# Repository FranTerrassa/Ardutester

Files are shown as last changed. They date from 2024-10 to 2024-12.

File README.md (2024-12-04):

## Projecto: {Ardutester}

Un comprobador de componentes Arduino basado en https://create.arduino.cc/projecthub/plouc68000/ardutester-v1-13-the-arduino-uno-transistor-tester-dbafb4

El autor original de este proyecto es [plouc68000](https://projecthub.arduino.cc/plouc68000) quien hizo el diseño y el codigo ardutester v1.13, aquien le doy todo el agradecimiento por este proyecto para la comunidad. También se a consultado este otro link [Mundo Yakara](https://www.youtube.com/watch?v=iBbuWZ-2Ljg&t=707sNo), gracias yakara por esos grandes videos. No es un proyecto propio, pero si he diseñado la PCB y fabricado siguiendo el esquema original.

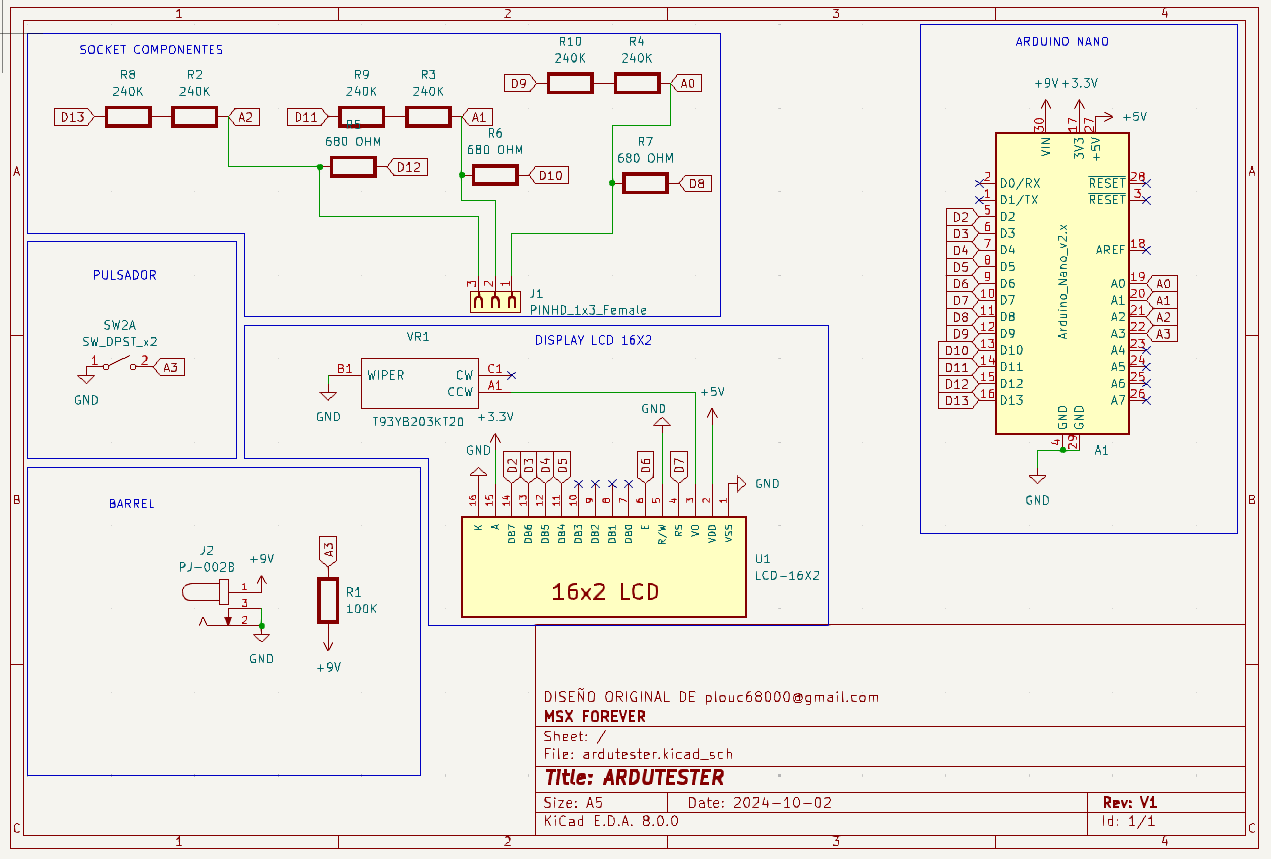
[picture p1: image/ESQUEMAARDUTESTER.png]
Esquema


La pcb esta diseñada para ser lo más pequeña y manejable posible. Se alimenta de 9v, por debajo de ese voltaje podría dar malos resultados.
Se a optado por resistencias SMD 1206 1/4w por el espacio que ocupan y no siendo muy dificiles de soldar para usuario medio y se a agregado una resistencia variable de 2k, (VR1) para ajustar el contraste de la pantalla.

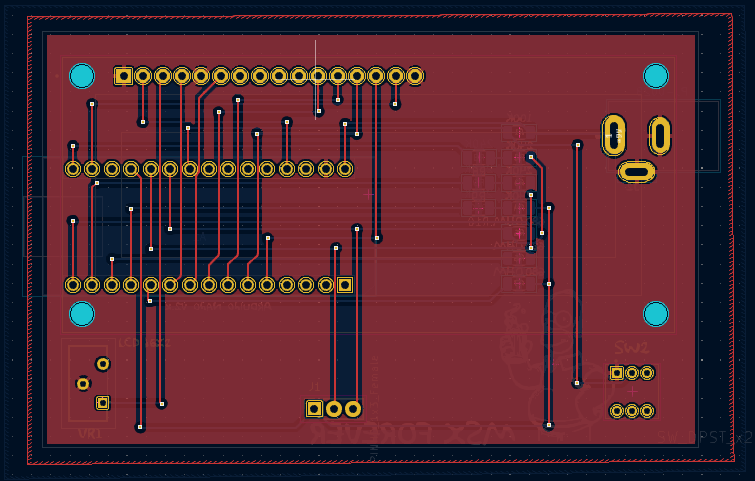
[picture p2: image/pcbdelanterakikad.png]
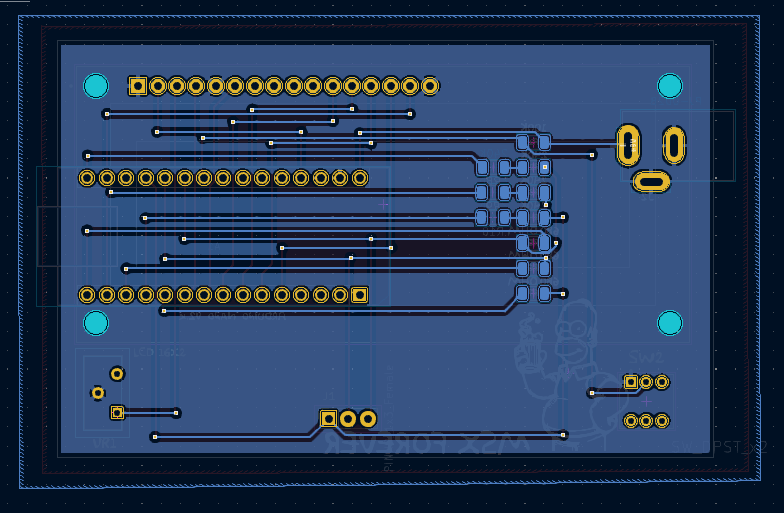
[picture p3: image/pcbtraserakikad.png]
 

El resultado lo vemos en las siguientes imagenes.

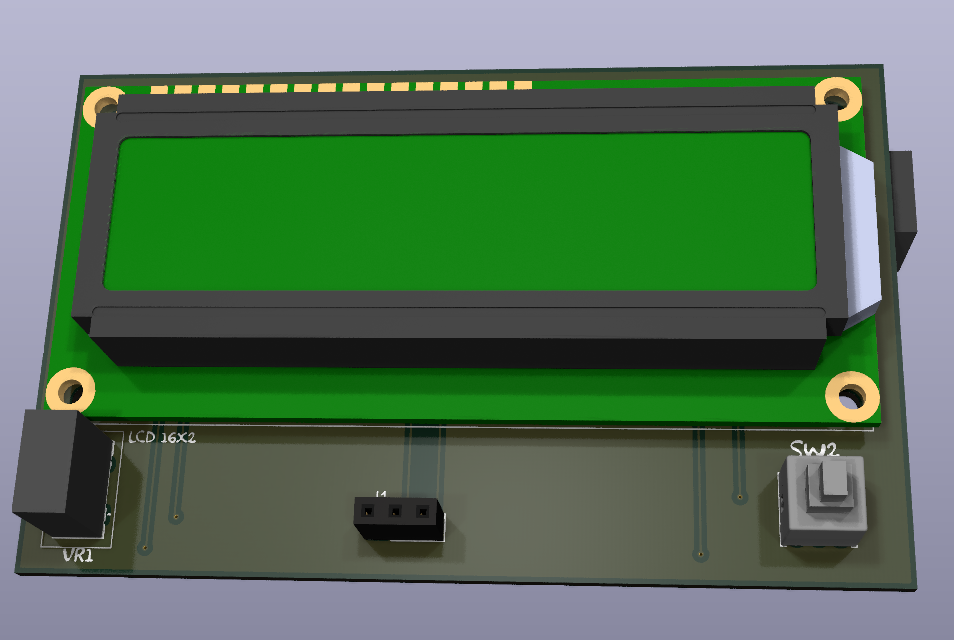
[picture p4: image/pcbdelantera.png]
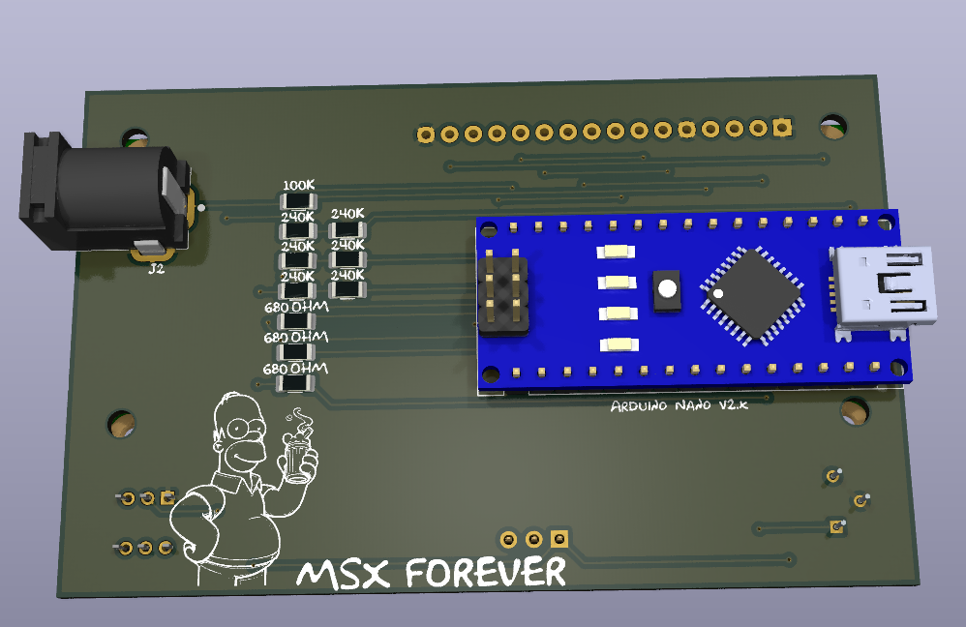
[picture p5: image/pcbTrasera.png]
 

## La caja 3D

Ha sido diseñada desde tinkercad es un modelo sencillo, pero agradable en tamaño y sencillez. Yo la he impreso en PLA con una boquilla 0.2, con un relleno de 20% y una altura de capa de 0.14.

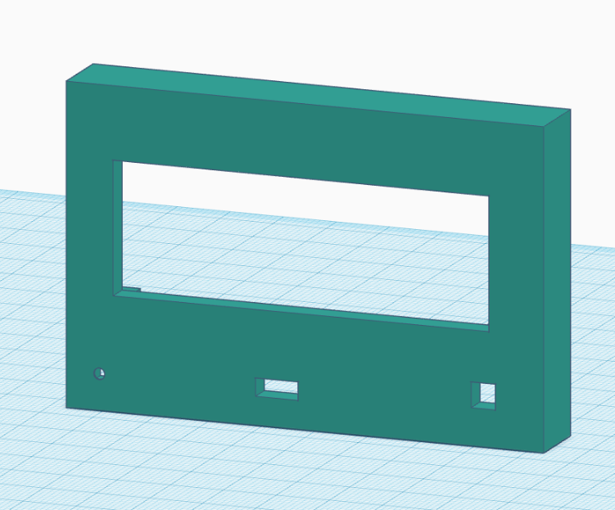
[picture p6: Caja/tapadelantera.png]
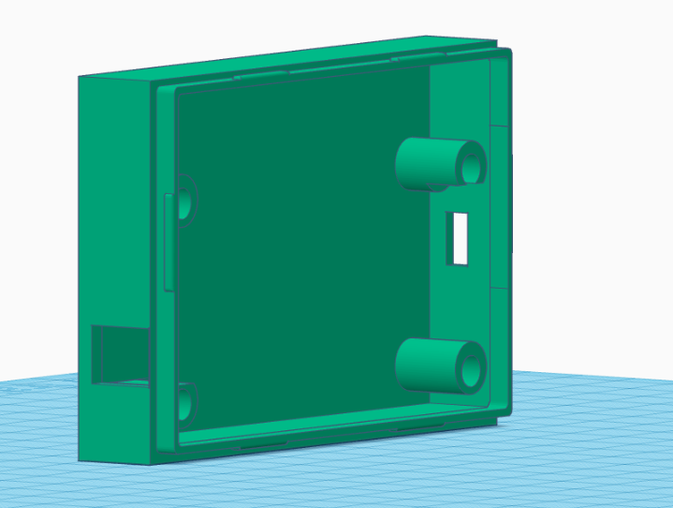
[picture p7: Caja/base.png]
 

Aquí se puede ver como queda el modelo montado.

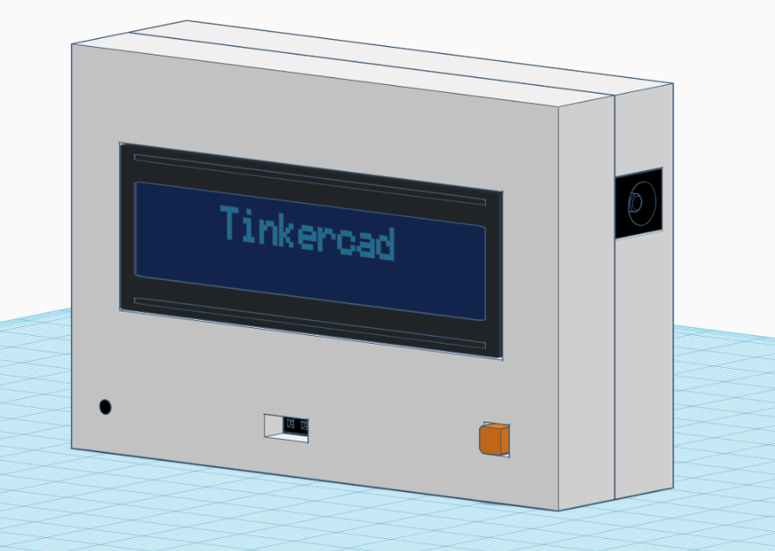
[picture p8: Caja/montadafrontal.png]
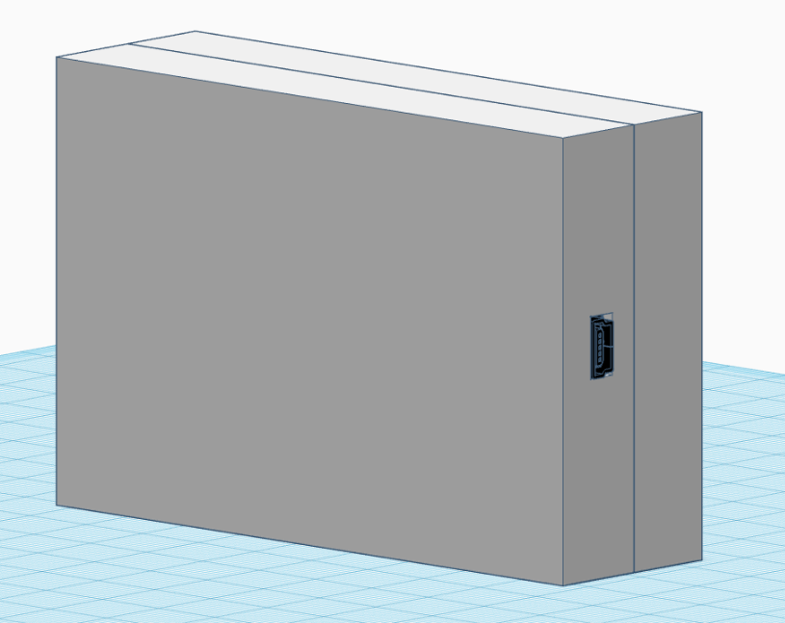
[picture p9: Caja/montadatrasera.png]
 

## Lista de materiales

|  ID |  Part name | Part number | Quantity |
|---|---|---|---|
| |  [Pin Header 1x06 2.54mm](https://es.aliexpress.com/item/32973181162.html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)| | 2 |
|  A1 | [Arduino Nano USB Mini](https://es.aliexpress.com/item/1005007066680464.html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) | | 1 |
|  U1 | [LCD Module 16x2](https://es.aliexpress.com/item/1005002035425652.html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) | | 1 |
|R2-R4,R8-R10| [Resistor 680 Ohm SMD 1/4W](https://es.aliexpress.com/item/1005006119604970.html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) | | 3 |
|R5-R7 | [Resistor 240 kOhm SMD 1/4W](https://es.aliexpress.com/item/1005006119604970.html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)| | 6 |
|  R1 | [Resistor 100 kOhm SMD 1/4W](https://es.aliexpress.com/item/1005006119604970.html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)| | 1 |
|  VR1 | [Pot. 2 khm](https://www.mouser.es/ProductDetail/Vishay-Sfernice/T93YB202KT20?qs=QKF3unAkNR%252BlfAchrMW0cA%3D%3D) y tambien [aquí*](https://es.aliexpress.com/item/1005005912140839.html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) | T93YB 2K  | 1 | 
|  SW | [Test Button](https://es.aliexpress.com/item/1703067548.html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) |TL2230EEF100 | 1 |
|  J2 | [Barrel](https://es.aliexpress.com/item/32974707992.html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) | PJ-002B | 1 | 
|  J1 | [Pin Socket 1x03 2.54mm](https://es.aliexpress.com/item/4001198421663.html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) | | 1 |

*Las medidas deben ser iguales pero no lo aseguro.

## Paso 1: Instalación

1. Abre el archivo de arduino ArduTester_1_13.ino.
2. Conecta el arduino nano y elige puerto correcto.
3. Clica sobre la flecha y espera a que cargue el codigo, una vez cargado ya puedes retirar el arduino y cerrar el programa.

## Paso 2: Montaje de componentes en la PCB

1. se suelda la parte trasera, lo que incluye Arduino, barrel y resistencias smd. Quedara ta que así.

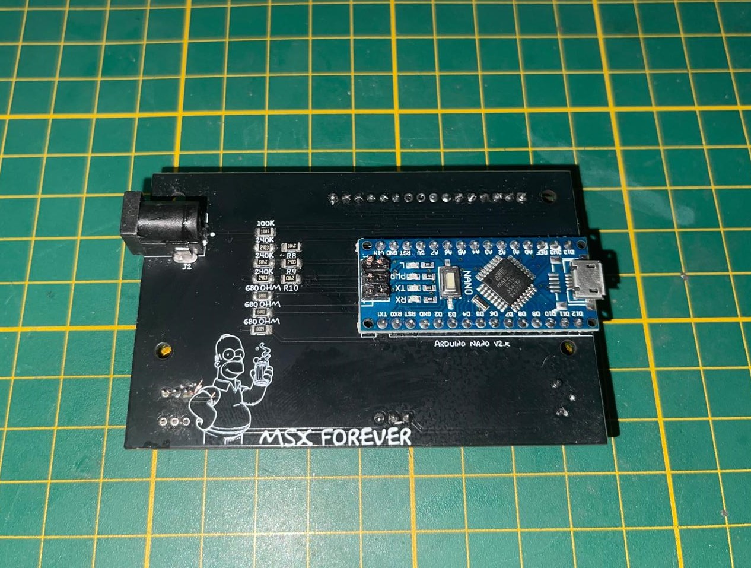
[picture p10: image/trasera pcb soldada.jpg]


2. Procederemos a las soldadura de la parte delantera, que incluye pantalla, pulsador, pinsocket y el potenciometro. Este sera el resultado.

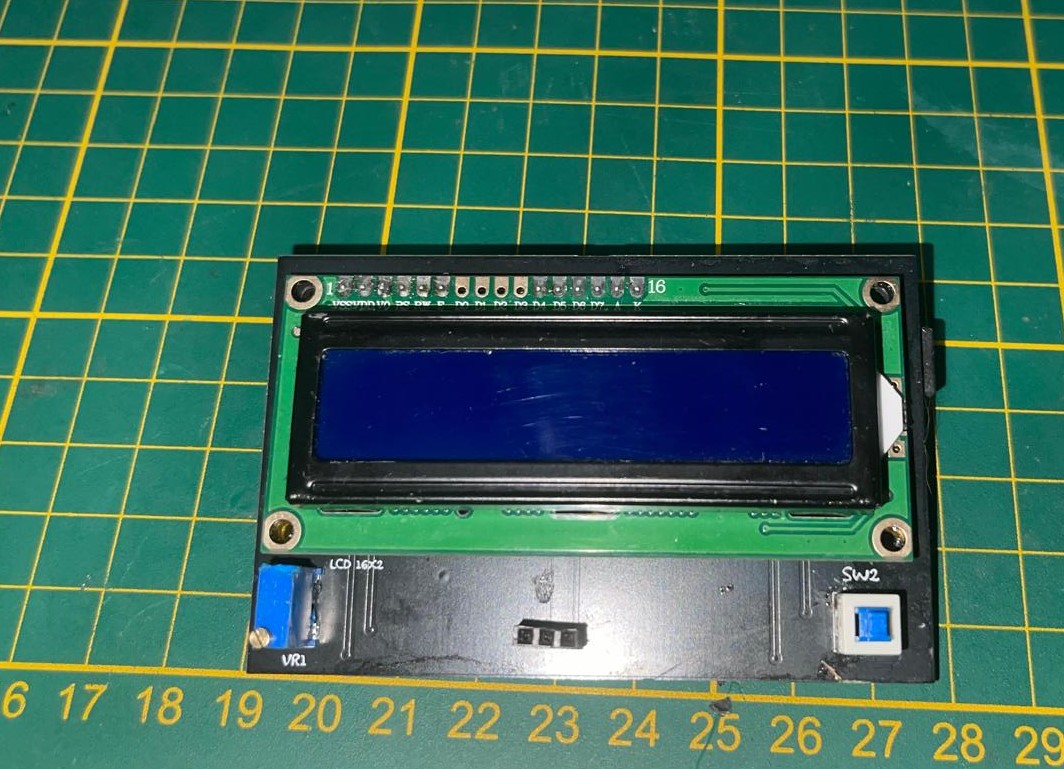
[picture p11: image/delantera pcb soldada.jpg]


3. una vez todo soldado, procedemos al montaje de la carcasa. Este es el resultado final, solo queda enchufarla a una fuente de alimentación de 9 voltios y a disfrutar.

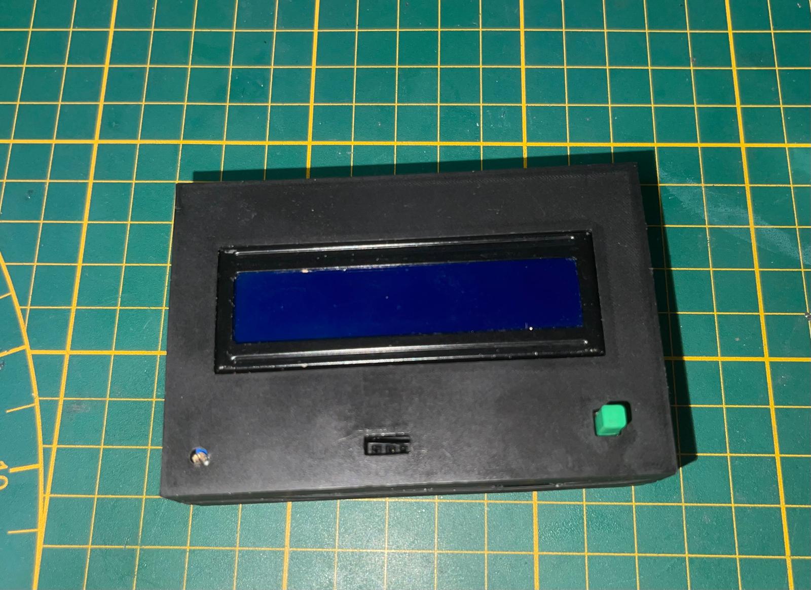
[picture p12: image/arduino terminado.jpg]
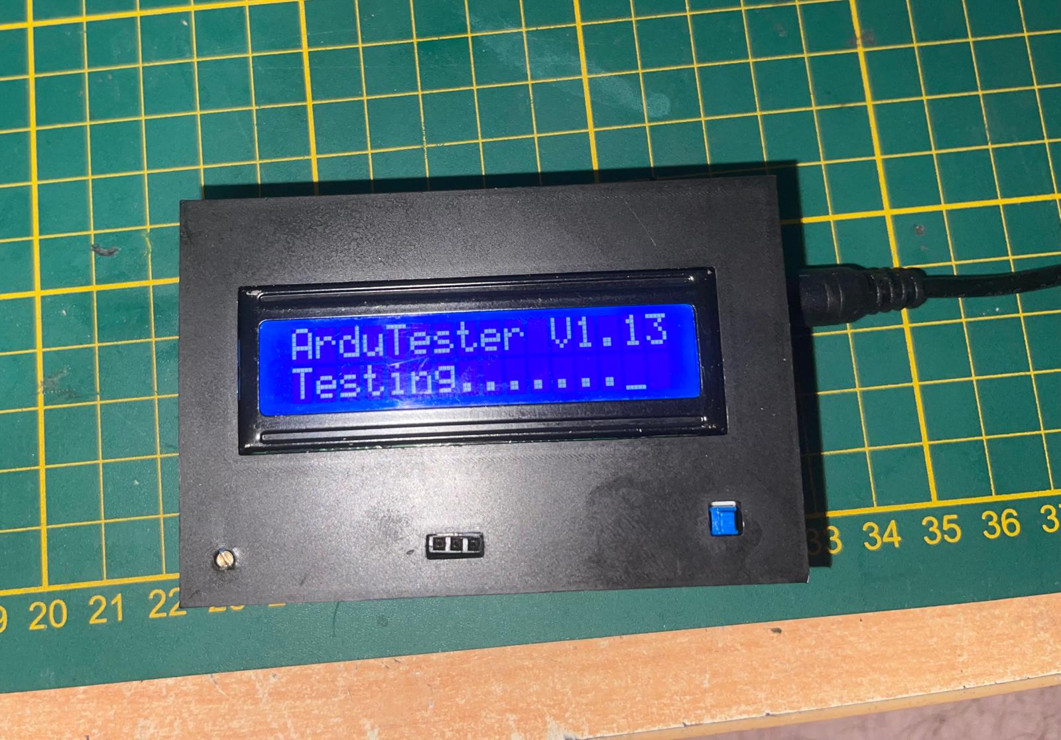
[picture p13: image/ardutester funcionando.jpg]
 

=== License
This project is released under a {OSHW} License.

=== Contributing
To contribute to this project please contact plouc68000 <plouc68000@gmail.com>

=== Help
This document is written in the _AsciiDoc_ format, a markup language to describe documents. 
If you need help you can search the http://www.methods.co.nz/asciidoc[AsciiDoc homepage]
or consult the http://powerman.name/doc/asciidoc[AsciiDoc cheatsheet]

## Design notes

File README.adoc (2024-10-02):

:Author: plouc68000
:Email: plouc68000@gmail.com
:Date: 14/10/2018
:Revision: ArduTester V1.13
:License: OSHW

= Project: {Ardutester}

image::pcb delantera.jpg[]

Porting of the files from TransistorTester V1.13 in the Arduino Editor, 
porting first to Arduino Mega, then to Arduino UNO.
The project uses widely the files posted below, same filenames, just .ino files.

https://www.mikrocontroller.net/svnbrowser/transistortester/Software/trunk/

https://github.com/svn2github/transistortester/tree/master/Software/trunk

Description and credits you find here:
https://www.mikrocontroller.net/articles/AVR_Transistortester

También se a consultado este otro link https://www.youtube.com/watch?v=iBbuWZ-2Ljg&t=707s[Mundo Yakara]

== Step 1: Installation

1. Open the file
2. Edit as you like
3. Release to the World!

== Step 2: Assemble the circuit

Assemble the circuit following this instruction:

1. Look at your Arduino/Genuino Uno pins:

-Pin ANALOG IN A0 (PC0) is TP1 ( ArduinoTester Pin 1 )
-Pin ANALOG IN A1 (PC1) is TP2 ( ArduinoTester Pin 2 ) 
-Pin ANALOG IN A2 (PC2) is TP3 ( ArduinoTester Pin 3 )

-Between A0 and DIGITAL 8 (PB0)  connect a 680 Ohm  Resistor
-Between A0 and DIGITAL 9 (PB1)  connect a 470 kOhm Resistor
-Between A1 and DIGITAL 10 (PB2) connect a 680 Ohm  Resistor
-Between A1 and GIGITAL 11 (PB3) connect a 470 kOhm Resistor
-Between A2 and DIGITAL 12 (PB4) connect a 680 Ohm  Resistor
-Between A1 and DIGITAL 13 (PB5) connect a 470 kOhm Resistor

-Pin ANALOG IN A3 to a 10 kOhm pullup Resistor at 5V and via the Test Button to GND

2. Look at your 2 Line LCD HD44780 Compatible ( 4 Bits Data ):

-Connect DIGITAL 5  to LCD DB4
-Connect DIGITAL 4  to LCD DB5
-Connect DIGITAL 3  to LCD DB6
-Connect DIGITAL 2  to LCD DB7
-Connect DIGITAL 7  to LCD RS
-Connect DIGITAL 6  to LCD E

-LCD LED- to GND
-LCD LED+ to 3,3V
-LCD VDD  to 5V
-LCD VSS  to GND
-LCD R/W  to GND
-LCD VO   to 10 kOhm Pot. ( Contrast Adjust. )

== Step 3: Load the code

Select Arduino/Genuino Uno and
Upload the code contained in this sketch on to your board

=== Folder structure

....
 TT_1_13_UNO             => Arduino sketch folder
  ├── TT_13oct.ino       => main Arduino file
  ├── schematics.png     => (optional) if someone wants to do it ...
  ├── layout.png         => (optional) if someone wants to do it ...
  └── ReadMe.adoc        => this file
....

=== License
This project is released under a {OSHW} License.

=== Contributing
To contribute to this project please contact plouc68000 <plouc68000@gmail.com>

=== BOM
Add the bill of the materials you need for this project.

|===
|  ID        |  Part name                | Part number | Quantity |
|            | Pin Header 1x06 2.54mm    |             | 2        |https://es.aliexpress.com/item/32973181162.html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[Aliexpress]
|  A1        | Arduino Nano USB Mini     |             | 1        |https://es.aliexpress.com/item/1005007066680464.html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[Aliexpress]
|  U1        | LCD Module 16x2           |             | 1        |https://es.aliexpress.com/item/1005002035425652.html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[Aliexpress]
|R2-R4,R8-R10| Resistor 680 Ohm SMD 1/4W |             | 3        |https://es.aliexpress.com/item/1005006119604970.html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[Aliexpress]
|R5-R7       | Resistor 240 kOhm SMD 1/4W|             | 6        |https://es.aliexpress.com/item/1005006119604970.html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[Aliexpress]
|  R1        | Resistor 100 kOhm SMD 1/4W|             | 1        |https://es.aliexpress.com/item/1005006119604970.html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[Aliexpress]
|  VR1       | Pot. 200 khm              | T93YB 200K  | 1        |https://www.mouser.es/ProductDetail/Vishay-Sfernice/T93YB-200K-10-TU?qs=BJgd0gnappXpszE2a8ZIhw%3D%3D[Mouser] 
|  SW        | Test Button               |TL2230EEF100 | 1        | https://es.aliexpress.com/item/1703067548.html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[Aliexpress]
|  J2        | Barrel                    |   PJ-002B   | 1        |     https://es.aliexpress.com/item/32974707992.html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[Aliexpress]     
|  J1        | Pin Socket 1x03 2.54mm    |             | 1        | https://es.aliexpress.com/item/4001198421663.html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[Aliexpress]        
|===

=== Help
This document is written in the _AsciiDoc_ format, a markup language to describe documents. 
If you need help you can search the http://www.methods.co.nz/asciidoc[AsciiDoc homepage]
or consult the http://powerman.name/doc/asciidoc[AsciiDoc cheatsheet]

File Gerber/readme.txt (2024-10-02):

Archivo Gerber para su producción. Grosor de placa 1.6, si es de más grosor no entrará en la caja. Se adjunta archivo bom.pdf con materiales enlazados, por supuesto los puedes comprar donde quieras.

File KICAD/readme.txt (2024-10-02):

Archivos para edición de placa y librerías para este proyecto.

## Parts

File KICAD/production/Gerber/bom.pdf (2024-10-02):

1 Arduino_Nano
1 PinSocket 1x03 P2.54mm Vertical (https://es.aliexpress.com/item/4001198421663.html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) 2 PinHeader 1x06 P2.54mm Vertical (https://es.aliexpress.com/item/32973181162.html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)
1 PJ-002B (https://es.aliexpress.com/item/32974707992.html)
1 Resistencia 1206 de 100K 1/4W (https://es.aliexpress.com/item/1005006119604970.html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)
6 Resistencia 1206 de 240k 1/4W (R10, R2, R3, R4, R8, R9) (https://es.aliexpress.com/item/1005006119604970.html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) 3 Resistencias 1206 680 1/4W (R5, R6, R7) (https://es.aliexpress.com/item/1005006119604970.html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)
1 TL2230EEF100 pulsador 7x7 (https://es.aliexpress.com/item/1703067548.html)
1 MODULE_LCD-16X2 (https://es.aliexpress.com/item/1005002035425652.html)
1 Resistencia regulable 200K (para contraste de LCD) (https://www.mouser.es/ProductDetail/Vishay-Sfernice/T93YB-200K-10-TU?qs=BJgd0gnappXpszE2a8ZIhw%3D%3D)

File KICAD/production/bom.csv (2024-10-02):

Designator | Footprint | Quantity | Value | LCSC Part #
A1 | Arduino_Nano | 1 | Arduino_Nano_v2.x
J1 | PinSocket_1x03_P2.54mm_Vertical | 1 | PINHD_1x3_Female
J2 | CUI_PJ-002B | 1 | PJ-002B
R1 | 1206 | 1 | 100K
R10, R2, R3, R4, R8, R9 | 1206 | 6 | 240K
R5, R6, R7 | 1206 | 3 | 680 OHM
SW2 | SW_TL2230EEF100 | 1 | SW_DPST_x2
U1 | MODULE_LCD-16X2 | 1 | LCD-16X2
VR1 | T93YB203KT20 | 1 | T93YB203KT20

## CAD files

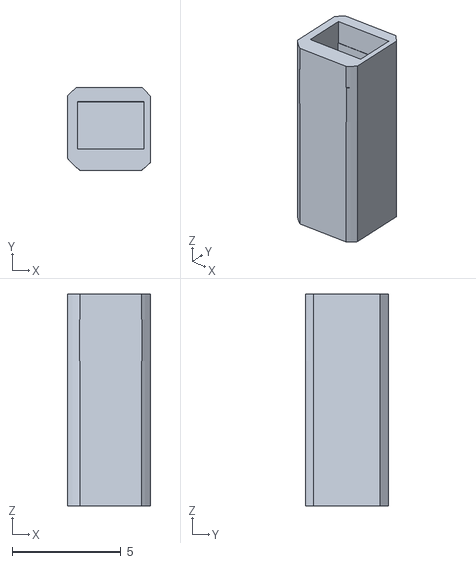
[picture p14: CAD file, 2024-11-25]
Caja/boton.stl
3.80 x 3.80 x 9.74

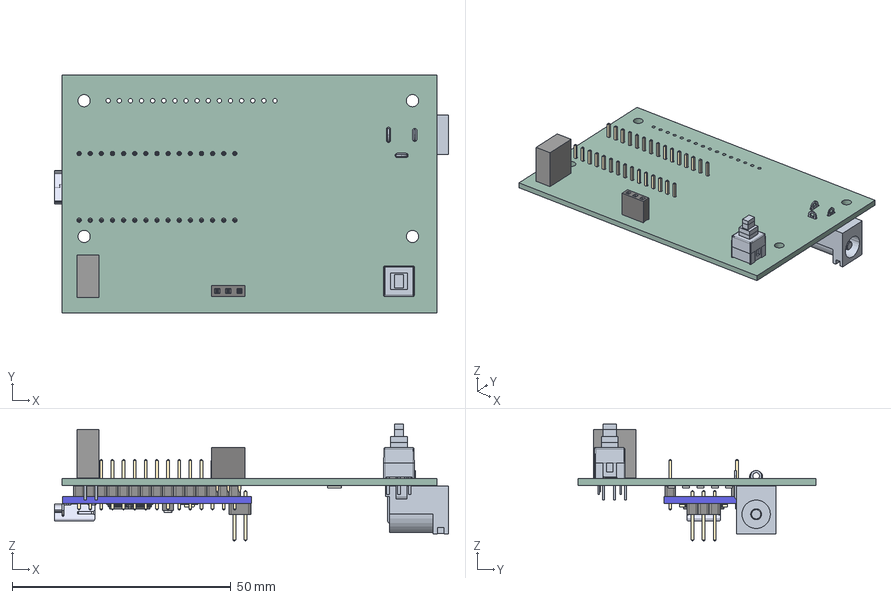
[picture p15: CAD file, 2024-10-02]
KICAD/ardutester.step
90.0 x 54.4 x 26.7 mm
ASSEMBLY
LatchSwitch_7x7
PinSocket_1x03_P254mm_Vertical
ARDUINO NANO 3.0
R_1206_3216Metric x 7
PJ-002B
ardutester mio_PCB

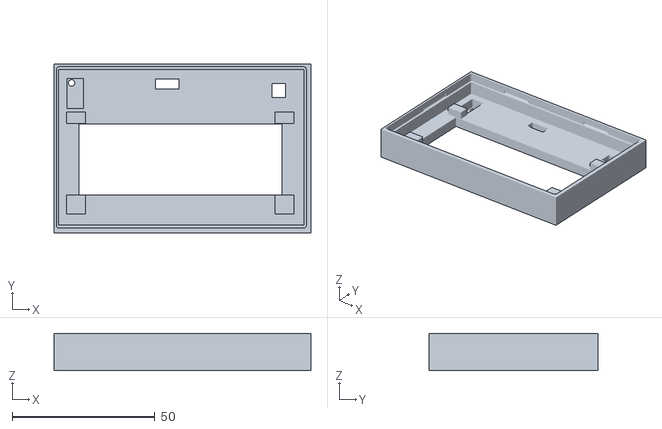
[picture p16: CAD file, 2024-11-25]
Caja/delantera.stl
89.9 x 59.1 x 13.0

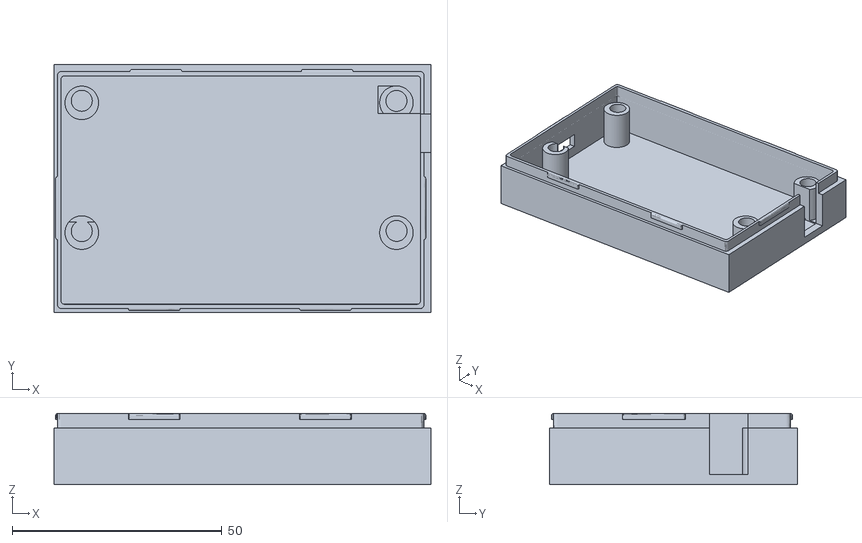
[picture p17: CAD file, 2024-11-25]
Caja/base.stl
89.9 x 59.1 x 17.0

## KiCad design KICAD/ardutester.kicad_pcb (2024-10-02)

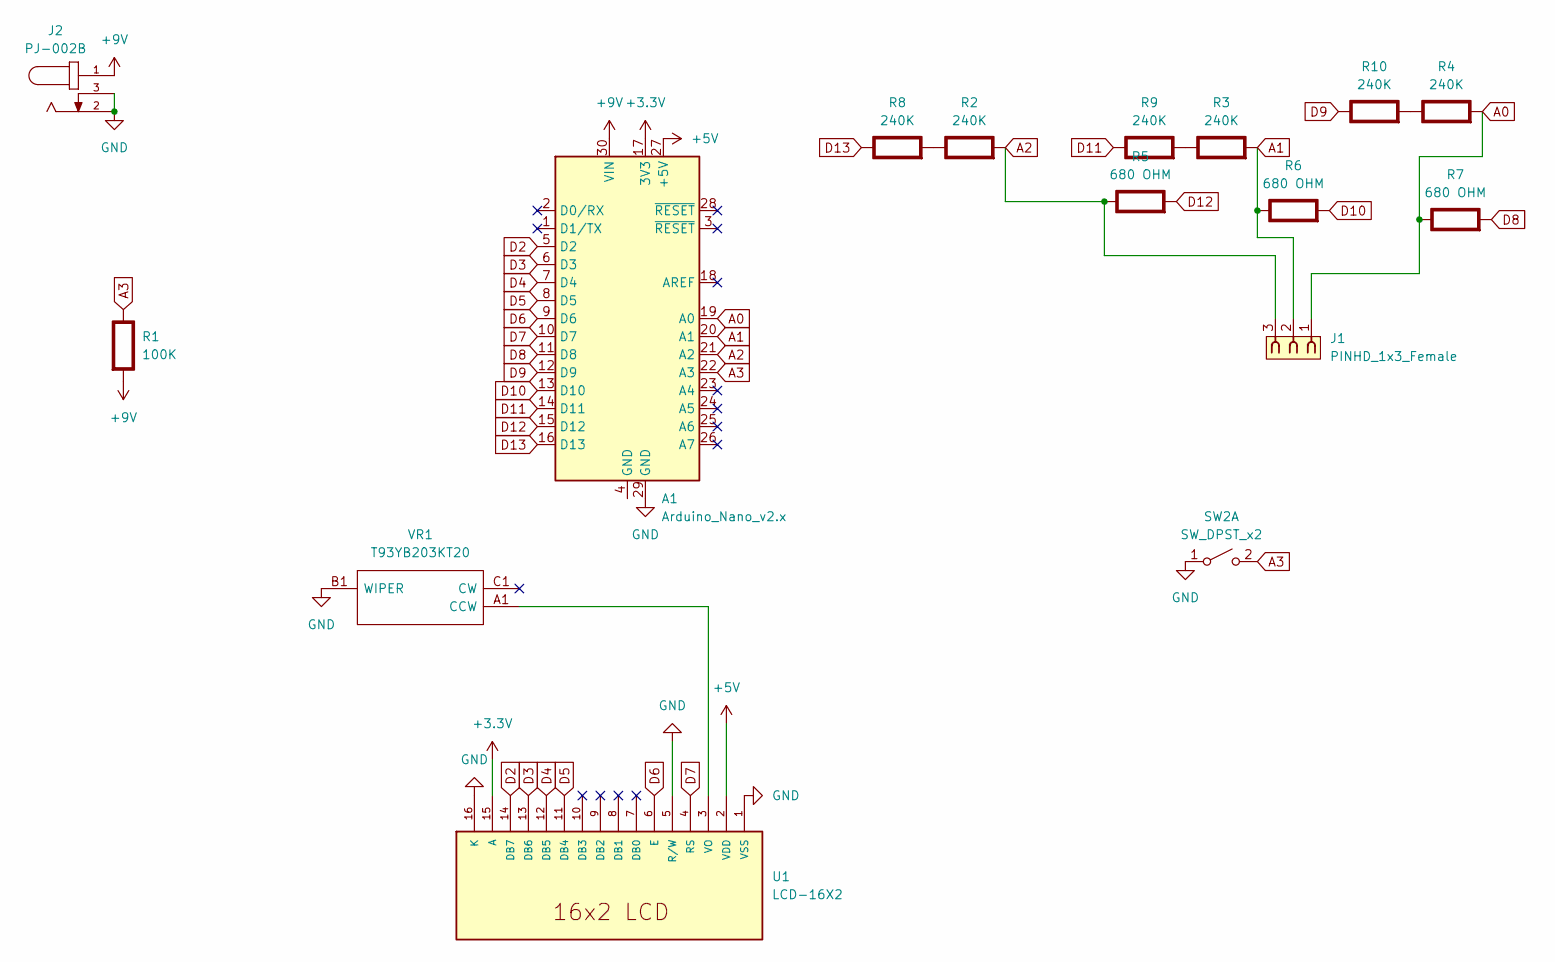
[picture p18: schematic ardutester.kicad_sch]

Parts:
A1: Arduino_Nano_v2.x; Arduino_Nano
J1: PINHD_1x3_Female; PinSocket_1x03_P2.54mm_Vertical
J2: PJ-002B; CUI_PJ-002B
R1: 100K; R_1206_3216Metric; Rating W
R2, R3, R4, R8, R9, R10: 240K; R_1206_3216Metric; Rating W
R5, R6, R7: 680 OHM; R_1206_3216Metric; Rating W
SW2: SW_DPST_x2; SW_TL2230EEF100
U1: LCD-16X2; MODULE_LCD-16X2; PARTREV N/A
VR1: T93YB203KT20; Manufacturer_Part_Number T93YB203KT20; Mouser Part Number 72-T93YB-20K

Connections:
+3.3V: A1.17 (3V3), U1.15 (A)
+5V: A1.27 (+5V), U1.2 (VDD)
+9V: A1.30 (VIN), J2.1, R1.2 (-)
A0: A1.19 (A0), J1.1, R4.2 (-), R7.1 (+)
A1: A1.20 (A1), J1.2, R3.2 (-), R6.1 (+)
A2: A1.21 (A2), J1.3, R2.2 (-), R5.1 (+)
A3: A1.22 (A3), R1.1 (+), SW2.2 (B)
D2: A1.5 (D2), U1.14 (DB7)
D3: A1.6 (D3), U1.13 (DB6)
D4: A1.7 (D4), U1.12 (DB5)
D5: A1.8 (D5), U1.11 (DB4)
D6: A1.9 (D6), U1.6 (E)
D7: A1.10 (D7), U1.4 (RS)
D8: A1.11 (D8), R7.2 (-)
D9: A1.12 (D9), R10.1 (+)
D10: A1.13 (D10), R6.2 (-)
D11: A1.14 (D11), R9.1 (+)
D12: A1.15 (D12), R5.2 (-)
D13: A1.16 (D13), R8.1 (+)
GND: A1.29 (GND), J2.2, J2.3, SW2.1 (A), U1.1 (VSS), U1.5 (R/W), U1.16 (K), VR1.B1 (WIPER)
unnamed: R2.1 (+), R8.2 (-)
unnamed: R3.1 (+), R9.2 (-)
unnamed: R4.1 (+), R10.2 (-)
unnamed: U1.3 (VO), VR1.A1 (CCW)

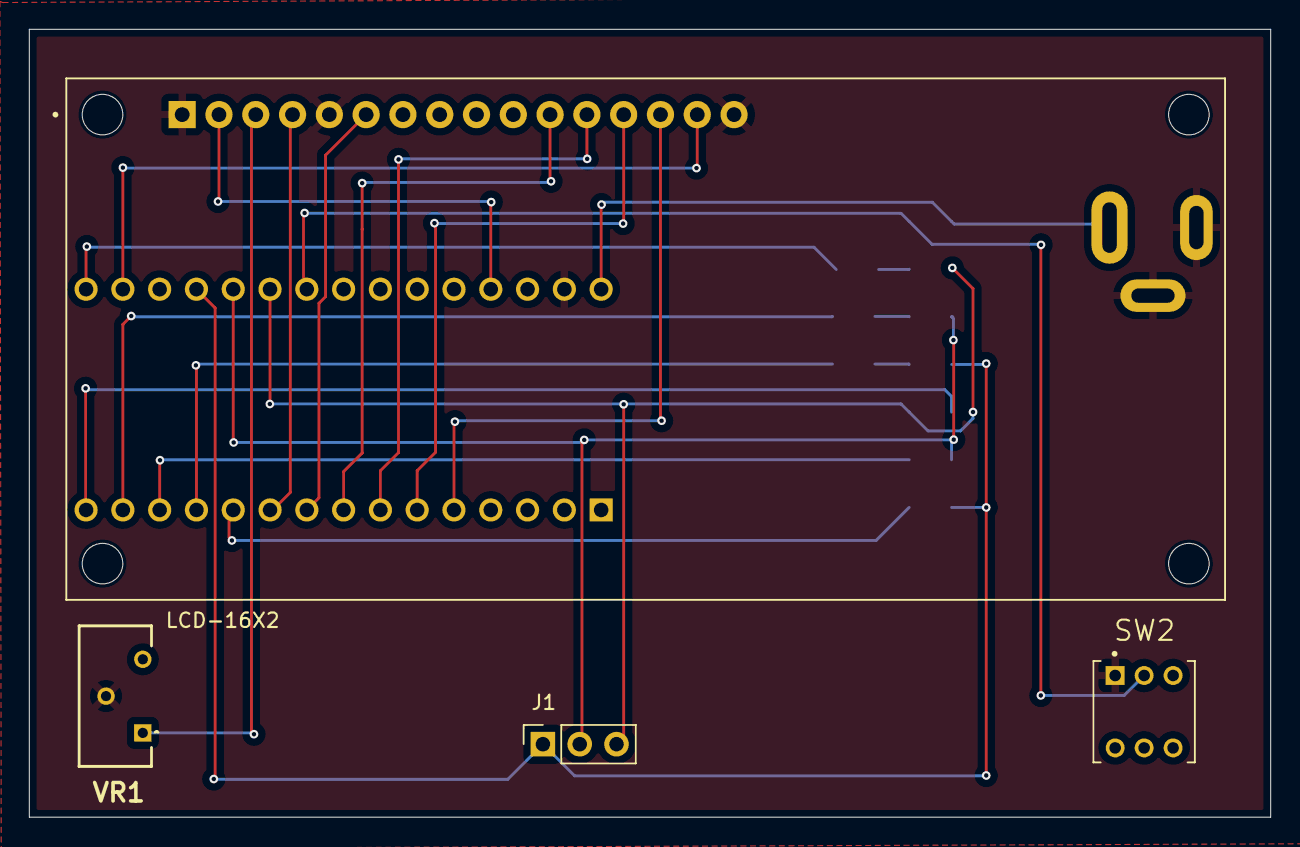
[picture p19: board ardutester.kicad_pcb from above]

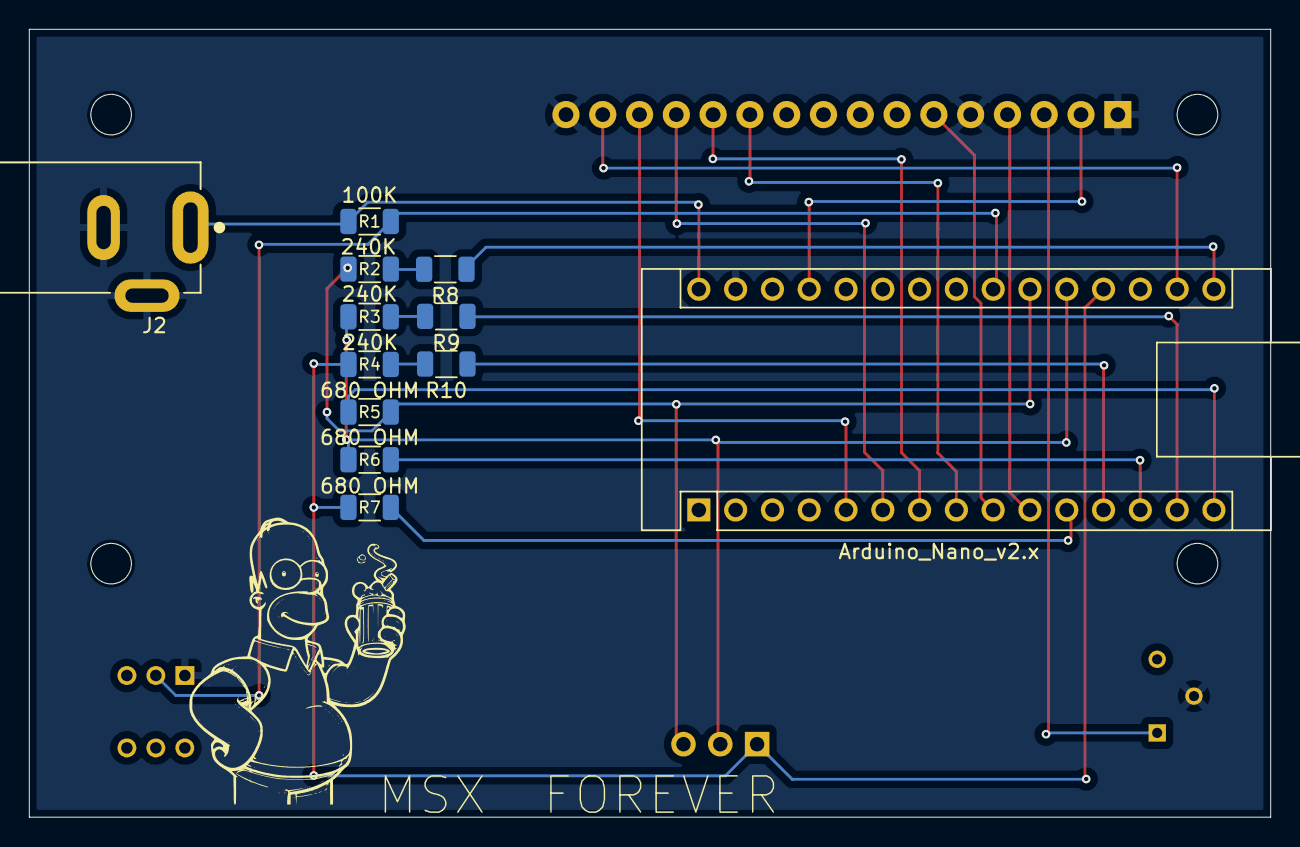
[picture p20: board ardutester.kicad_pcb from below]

Board: 2 copper layers, 85.7 x 54.4 mm, 16 parts (12 on the bottom side), 24 nets.

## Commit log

2024-10-01 Case
    Caja diseñada a medida para el circuito
2024-10-01 Caja 3D
    Diseño de caja 3D, para imprimir con boquilla 0.2 y a un 20% de relleno.
    [Ardutester frontal.stl]
2024-10-02 Add files via upload
    Caja 3d diseñada con Tinkercad para Ardutester. Imprimir con boquilla 0.2 a un 20% de relleno.
    [Ardutester botón.stl, Ardutester frontal.stl, Ardutester trasera.stl]
2024-10-02 Add files via upload
    Código arduino para insertar a Arduino nano
2024-10-02 Add files via upload
    Archivo gerber para la producción de PCB y lista bom. En la lista bom e añadido links para mas fácil adquisición del los componentes, en la resistencia regulable también las hay en aliexpress pero no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
2024-10-02 Add files via upload
    Gerber y archivo bom en pdf con links a componentes.
2024-10-02 Add files via upload
    Carpeta de imagenes
2024-11-25 Rename Imagen de WhatsApp 2024-11-25 a las 16.47.15_54525e8f.jpg to trasera pcb montada
